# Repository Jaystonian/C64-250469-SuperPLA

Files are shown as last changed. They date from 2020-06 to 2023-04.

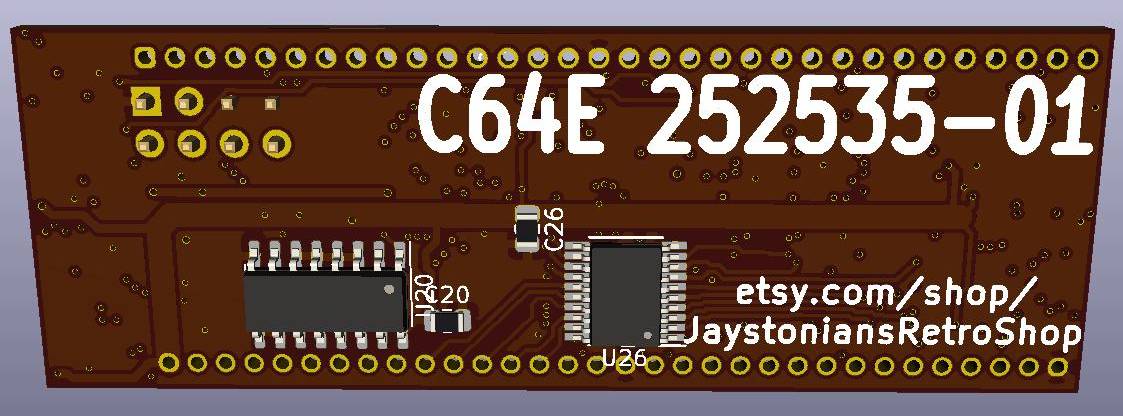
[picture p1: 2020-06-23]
img/C64CPLA-b.jpg

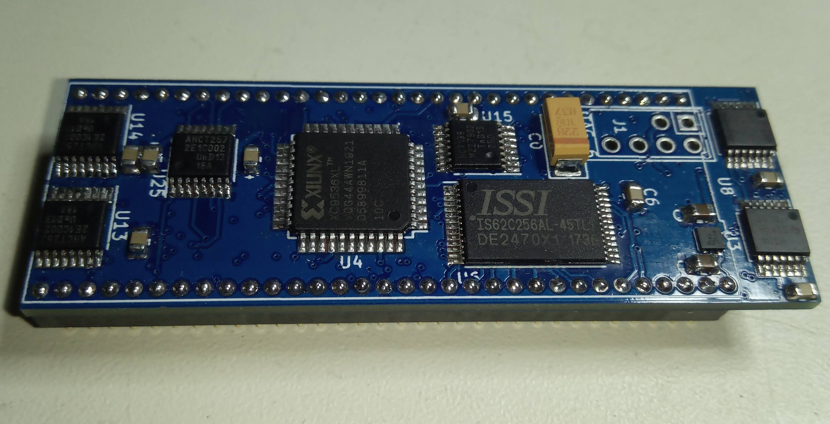
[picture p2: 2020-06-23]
img/IMG_20200623_193337_3.jpg

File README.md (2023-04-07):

# C64-250469-SuperPLA
Replacement board for a 251715-01 or 252535-01

I built one to test and topically it did not work, need to find time to understand why.  I suspect it was the AHCT chips, should use HCT.

Update 2023-04-07 The problem turns out to be the PCB's footprint for the SRAM, as Pin 1 is in the wrong location.

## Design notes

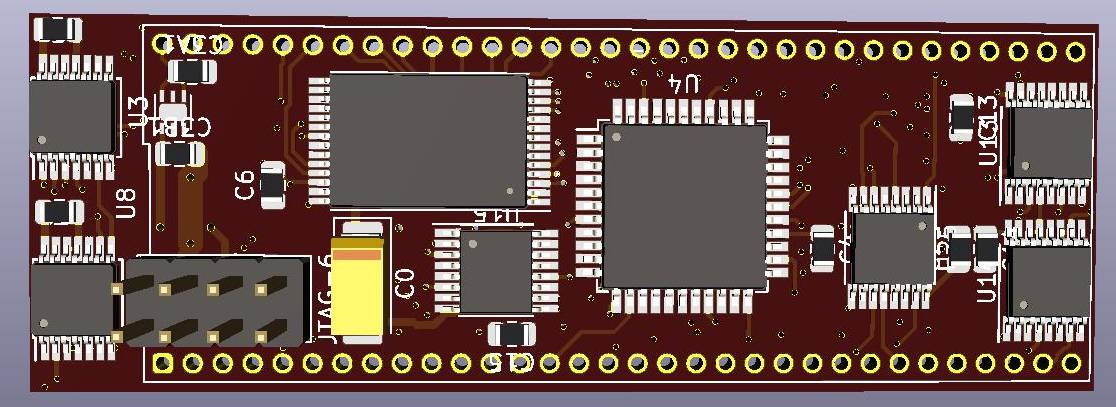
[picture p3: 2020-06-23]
img/C64CPLA-t.jpg

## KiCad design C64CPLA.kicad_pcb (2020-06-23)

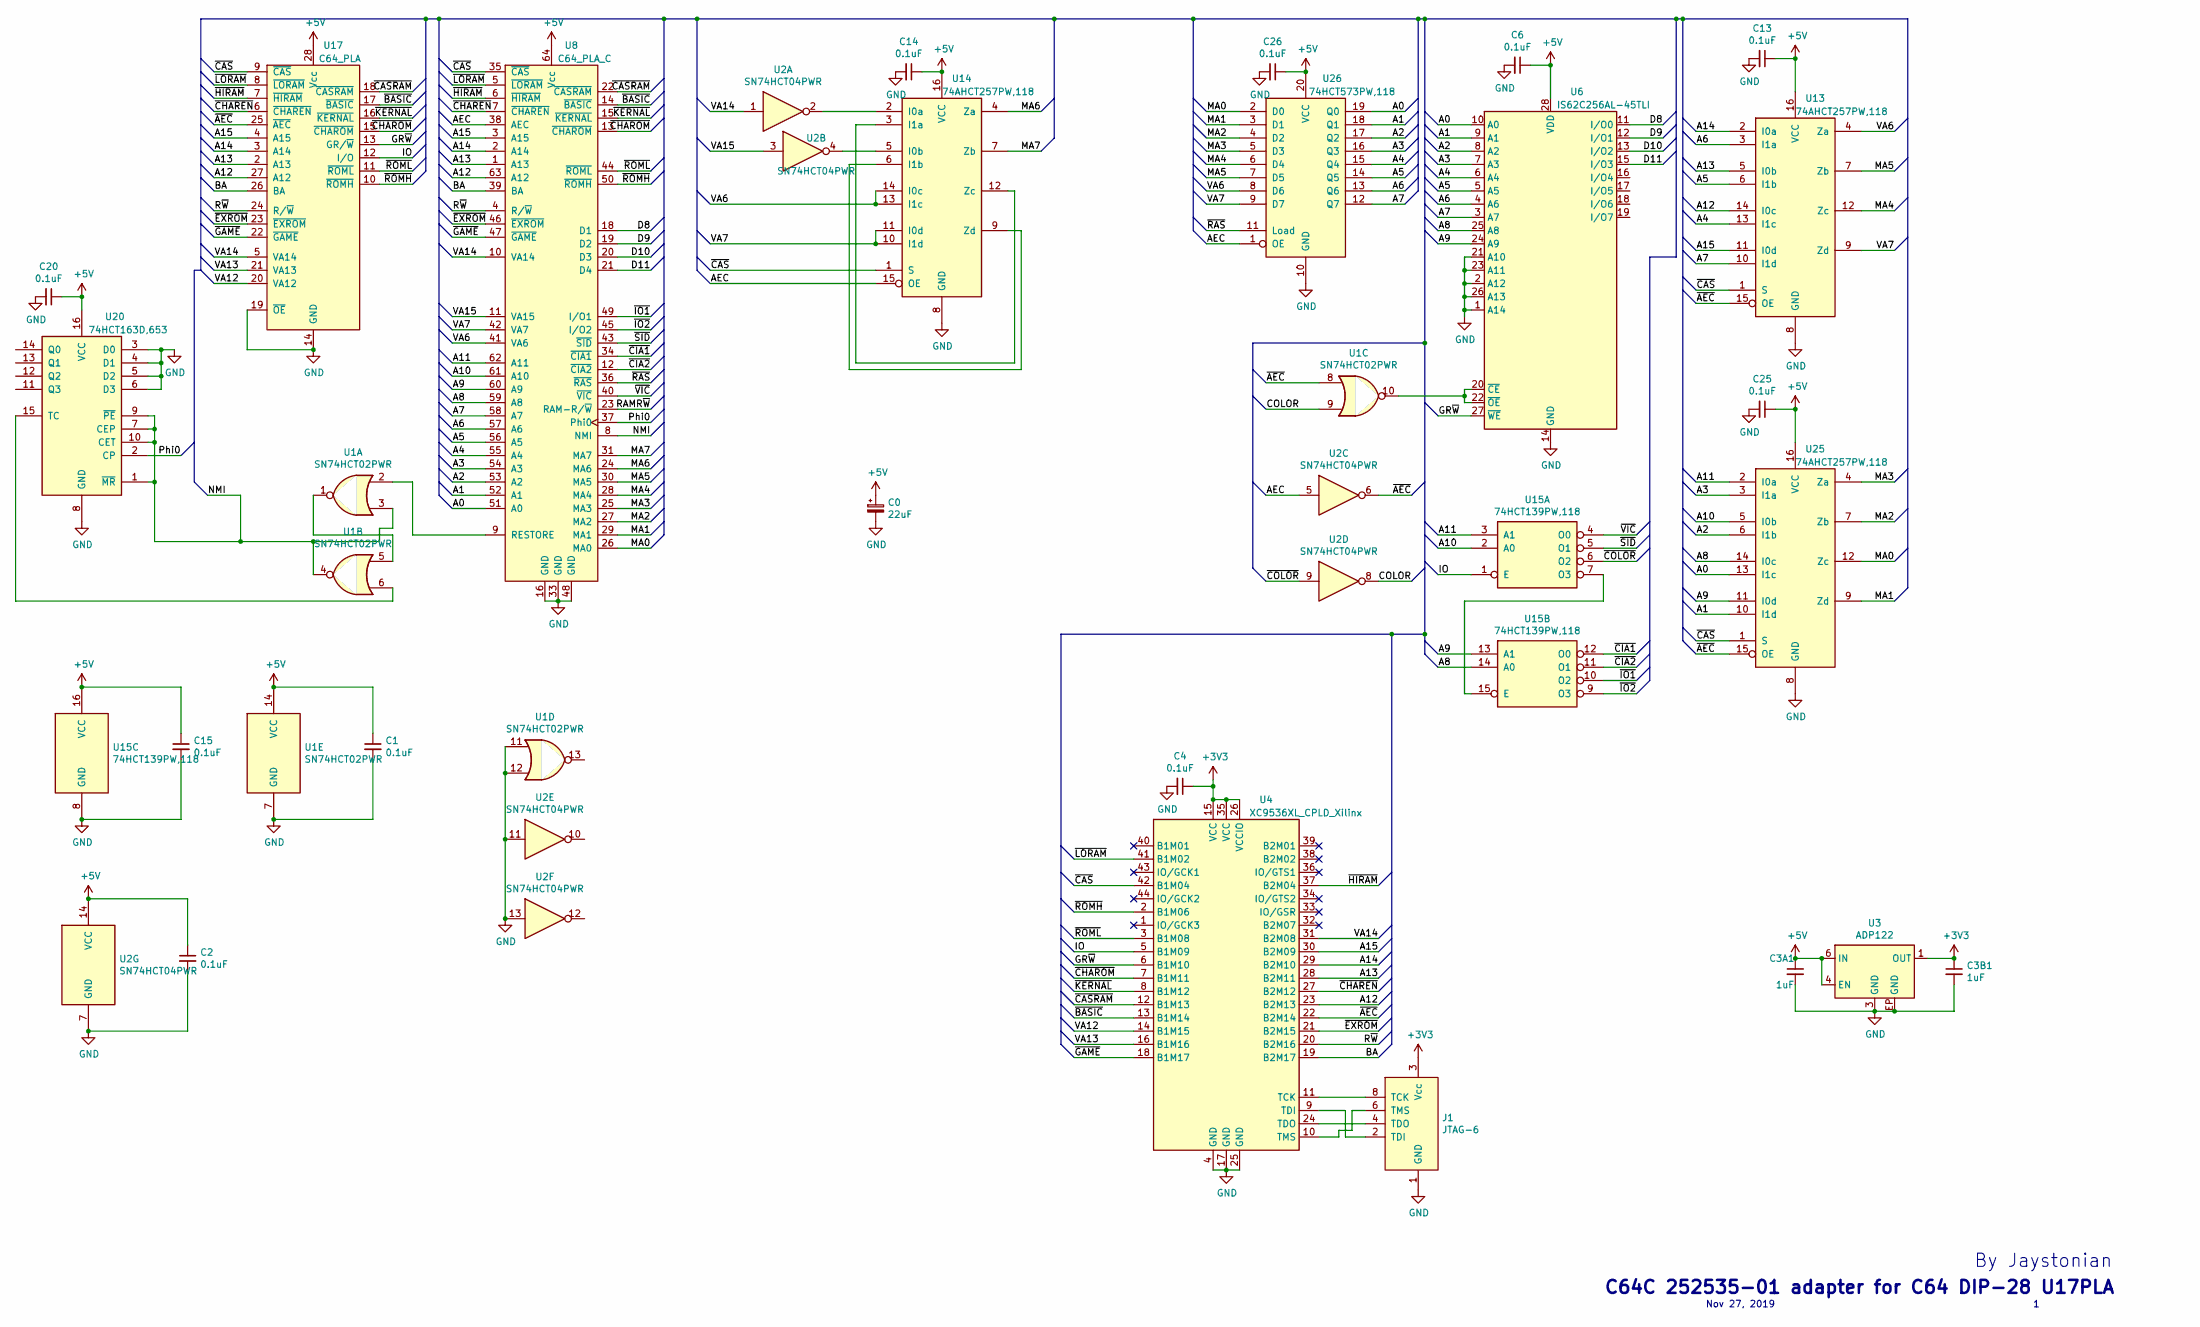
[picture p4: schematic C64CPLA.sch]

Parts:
C0: 22uF; CP_EIA-6032-28_Kemet-C_Pad2.25x2.35mm_HandSolder
C1, C2, C4, C6, C13, C14, C15, C20, C25, C26: 0.1uF; R_0805_2012Metric
C3A1, C3B1: 1uF; R_0805_2012Metric
J1: JTAG-6; PinHeader_2x04_P2.54mm_Vertical
U1: SN74HCT02PWR; TSSOP-14_4.4x5mm_P0.65mm
U2: SN74HCT04PWR; TSSOP-14_4.4x5mm_P0.65mm
U3: ADP122; LFCSP-6
U4: XC9536XL_CPLD_Xilinx; TQFP-44_10x10mm_P0.8mm
U6: IS62C256AL-45TLI; TSOP-I-28_11.8x8mm_P0.55mm
U8: C64_PLA_C; DIP-64_750
U13, U14, U25: 74AHCT257PW,118; TSSOP-16_4.4x5mm_P0.65mm
U15: 74HCT139PW,118; TSSOP-16_4.4x5mm_P0.65mm
U17: C64_PLA; DIP-28_W15.24mm
U20: 74HCT163D,653; SOIC-16_3.9x9.9mm_P1.27mm
U26: 74HCT573PW,118; TSSOP-20_4.4x6.5mm_P0.65mm

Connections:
+5V: C0.1, C1.1, C2.1, C3A1.1, C6.1, C13.1, C14.1, C15.1, C20.1, C25.1, C26.1, U1.14 (VCC), U2.14 (VCC), U3.4 (EN), U3.6 (IN), U6.28 (VDD), U8.64 (Vcc), U13.16 (VCC), U14.16 (VCC), U15.16 (VCC), U17.28 (Vcc), U20.16 (VCC), U25.16 (VCC), U26.20 (VCC)
/A0: U6.10 (A0), U8.51 (A0), U25.13 (I1c), U26.19 (Q0)
/A1: U6.9 (A1), U8.52 (A1), U25.10 (I1d), U26.18 (Q1)
/A2: U6.8 (A2), U8.53 (A2), U25.6 (I1b), U26.17 (Q2)
/A3: U6.7 (A3), U8.54 (A3), U25.3 (I1a), U26.16 (Q3)
/A4: U6.6 (A4), U8.55 (A4), U13.13 (I1c), U26.15 (Q4)
/A5: U6.5 (A5), U8.56 (A5), U13.6 (I1b), U26.14 (Q5)
/A6: U6.4 (A6), U8.57 (A6), U13.3 (I1a), U26.13 (Q6)
/A7: U6.3 (A7), U8.58 (A7), U13.10 (I1d), U26.12 (Q7)
/A8: U6.25 (A8), U8.59 (A8), U15.14 (A0), U25.14 (I0c)
/A9: U6.24 (A9), U8.60 (A9), U15.13 (A1), U25.11 (I0d)
/A10: U8.61 (A10), U15.2 (A0), U25.5 (I0b)
/A11: U8.62 (A11), U15.3 (A1), U25.2 (I0a)
/A12: U4.23 (B2M13), U8.63 (A12), U13.14 (I0c), U17.27 (A12)
/A13: U4.28 (B2M11), U8.1 (A13), U13.5 (I0b), U17.2 (A13)
/A14: U4.29 (B2M10), U8.2 (A14), U13.2 (I0a), U17.3 (A14)
/A15: U4.30 (B2M09), U8.3 (A15), U13.11 (I0d), U17.4 (A15)
/AEC: U2.5, U8.38 (AEC), U14.15 (OE), U26.1 (OE)
/BA: U4.19 (B2M17), U8.39 (BA), U17.26 (BA)
/COLOR: U1.9, U2.8
/D8: U6.11 (I/O0), U8.18 (D1)
/D9: U6.12 (I/O1), U8.19 (D2)
/D10: U6.13 (I/O2), U8.20 (D3)
/D11: U6.15 (I/O3), U8.21 (D4)
/GR~W: U4.6 (B1M10), U6.27 (~WE), U17.13 (GR/~W~)
/IO: U4.5 (B1M09), U15.1 (E), U17.12 (I/O)
/MA0: U8.26 (MA0), U25.12 (Zc), U26.2 (D0)
/MA1: U8.29 (MA1), U25.9 (Zd), U26.3 (D1)
/MA2: U8.27 (MA2), U25.7 (Zb), U26.4 (D2)
/MA3: U8.25 (MA3), U25.4 (Za), U26.5 (D3)
/MA4: U8.28 (MA4), U13.12 (Zc), U26.6 (D4)
/MA5: U8.30 (MA5), U13.7 (Zb), U26.7 (D5)
/MA6: U8.24 (MA6), U14.4 (Za)
/MA7: U8.31 (MA7), U14.7 (Zb)
/NMI: U1.3, U1.4, U8.8 (NMI), U20.1 (~MR), U20.7 (CEP), U20.9 (~PE), U20.10 (CET)
/Phi0: U8.37 (Phi0), U20.2 (CP)
/RAMR~W: U8.23 (RAM-R/~W)
/R~W: U4.20 (B2M16), U8.4 (R/~W), U17.24 (R/~W~)
/VA6: U8.41 (VA6), U13.4 (Za), U14.13 (I1c), U14.14 (I0c), U26.8 (D6)
/VA7: U8.42 (VA7), U13.9 (Zd), U14.10 (I1d), U14.11 (I0d), U26.9 (D7)
/VA12: U4.14 (B1M15), U17.20 (VA12)
/VA13: U4.16 (B1M16), U17.21 (VA13)
/VA14: U2.1, U4.31 (B2M08), U8.10 (VA14), U17.5 (VA14)
/VA15: U2.3, U8.11 (VA15)
/~AEC: U1.8, U2.6, U4.22 (B2M14), U13.15 (OE), U17.25 (~AEC), U25.15 (OE)
/~BASIC: U4.13 (B1M14), U8.14 (~BASIC~), U17.17 (~BASIC~)
/~CAS: U4.42 (B1M04), U8.35 (~CAS), U13.1 (S), U14.1 (S), U17.9 (~CAS), U25.1 (S)
/~CASRAM: U4.12 (B1M13), U8.22 (~CASRAM~), U17.18 (~CASRAM~)
/~CHAREN: U4.27 (B2M12), U8.7 (~CHAREN), U17.6 (~CHAREN)
/~CHAROM: U4.7 (B1M11), U8.13 (~CHAROM~), U17.15 (~CHAROM~)
/~CIA1: U8.34 (~CIA1), U15.12 (O0)
/~CIA2: U8.12 (~CIA2), U15.11 (O1)
/~COLOR: U2.9, U15.6 (O2)
/~EXROM: U4.21 (B2M15), U8.46 (~EXROM~), U17.23 (~EXROM~)
/~GAME: U4.18 (B1M17), U8.47 (~GAME~), U17.22 (~GAME~)
/~HIRAM: U4.37 (B2M04), U8.6 (~HIRAM), U17.7 (~HIRAM)
/~IO1: U8.49 (I/O1), U15.10 (O2)
/~IO2: U8.45 (I/O2), U15.9 (O3)
/~KERNAL: U4.8 (B1M12), U8.15 (~KERNAL~), U17.16 (~KERNAL~)
/~LORAM: U4.41 (B1M02), U8.5 (~LORAM), U17.8 (~LORAM)
/~RAS: U8.36 (~RAS), U26.11 (Load)
/~ROMH: U4.2 (B1M06), U8.50 (~ROMH), U17.10 (~ROMH~)
/~ROML: U4.3 (B1M08), U8.44 (~ROML), U17.11 (~ROML~)
/~SID: U8.43 (~SID), U15.5 (O1)
/~VIC: U8.40 (~VIC), U15.4 (O0)
GND: C0.2, C1.2, C2.2, C3A1.2, C3B1.2, C4.2, C6.2, C13.2, C14.2, C15.2, C20.2, C25.2, C26.2, J1.1 (GND), U1.7 (GND), U1.11, U1.12, U2.7 (GND), U2.11, U2.13, U3.3 (GND), U3.EP (GND), U4.4 (GND), U4.17 (GND), U4.25 (GND), U6.1 (A14), U6.2 (A12), U6.14 (GND), U6.21 (A10), U6.23 (A11), U6.26 (A13), U8.16 (GND), U8.33 (GND), U8.48 (GND), U13.8 (GND), U14.8 (GND), U15.8 (GND), U17.14 (GND), U17.19 (~OE~), U20.3 (D0), U20.4 (D1), U20.5 (D2), U20.6 (D3), U20.8 (GND), U25.8 (GND), U26.10 (GND)
unnamed: J1.2 (TDI), U4.9 (TDI)
unnamed: J1.4 (TDO), U4.24 (TDO)
unnamed: J1.6 (TMS), U4.10 (TMS)
unnamed: J1.8 (TCK), U4.11 (TCK)
unnamed: U1.1, U1.5
unnamed: U1.2, U8.9 (RESTORE)
unnamed: U1.6, U20.15 (TC)
unnamed: U1.10, U6.20 (~CE), U6.22 (~OE)
unnamed: U2.2, U14.2 (I0a)
unnamed: U2.4, U14.5 (I0b)
unnamed: U14.6 (I1b), U14.9 (Zd)
unnamed: U14.3 (I1a), U14.12 (Zc)
unnamed: U15.7 (O3), U15.15 (E)

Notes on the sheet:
C64C 252535-01 adapter for C64 DIP-28 U17PLA
Nov 27, 2019
By Jaystonian

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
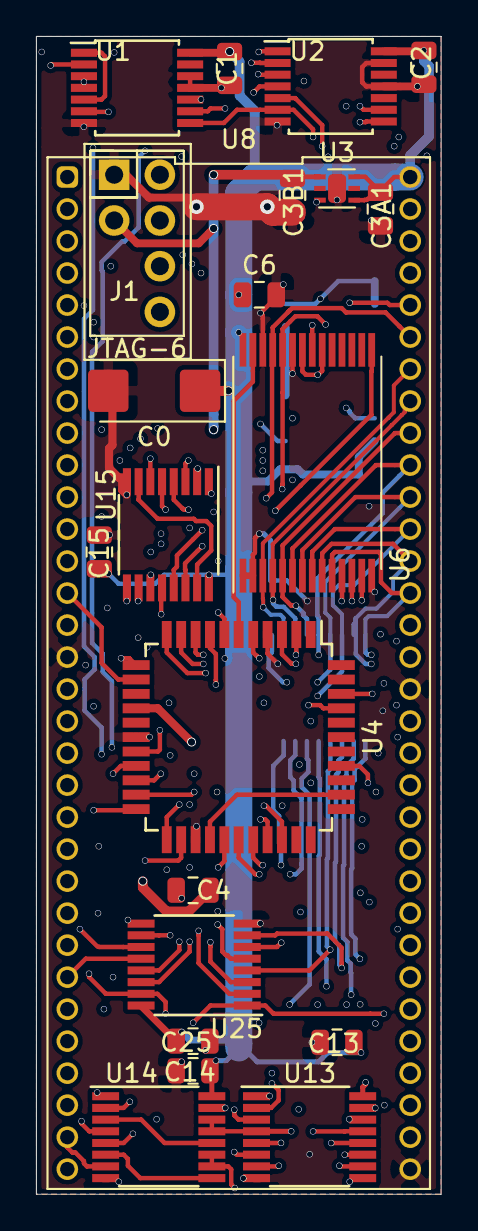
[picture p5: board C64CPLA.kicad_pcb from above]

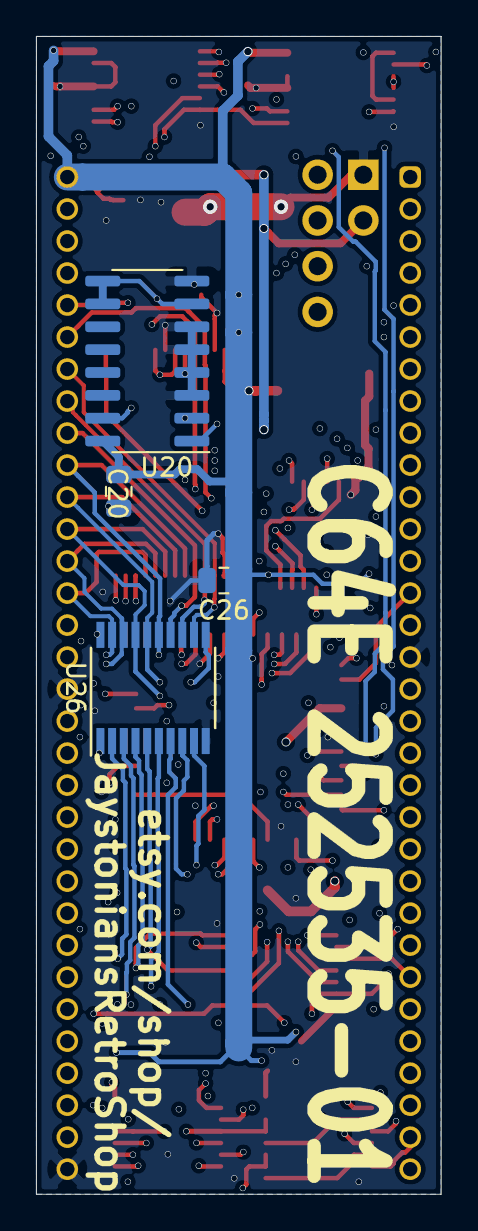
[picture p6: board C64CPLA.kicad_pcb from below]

Board: 6 copper layers, 22.5 x 64.3 mm, 26 parts (4 on the bottom side), 78 nets.
